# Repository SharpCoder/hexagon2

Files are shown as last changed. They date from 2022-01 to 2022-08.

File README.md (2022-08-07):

# hexagon2

Hexagon wall v2

Final product

## Installation

To properly build the hexagon2 project, you'll need the following:

```bash
# Install build tools
sudo apt-get install gcc-arm-none-eabi jq

# Configure rust
rustup default nightly
rustup target add thumbv7em-none-eabi
```

## Building

In order for your project to build correctly, you'll need to run the following command:

```
./build.sh
```

The build script will generate a `.hex` file and place it in a folder called `out`. This hex file is compatible with the teensy 4.0 and can be flashed with the teensy-loader utility.

**CAUTION**: Do not build this in release mode. It optimizes a lot of stuff away, and can cause problems.

## Bill of Materials

### Brain

- 1x [DC Barrel Jack](https://www.sparkfun.com/products/10811)
- 1x DS18B20
- 1x 4.5k Resistor
- 1x 100uf Capacitor
- 1x [ESP8266](https://www.amazon.com/dp/B010N1ROQS)
- 1x [Teensy4.0](https://www.sparkfun.com/products/16997)
- 3x [WS2812b SMD](https://www.sparkfun.com/products/16346)

### Unit

- 3x [WS2812b SMD](https://www.sparkfun.com/products/16346)
- 2x Right-Angle Headers

### Hardware (per unit)

- 1x M4x12 Bolt
- 1x M4 Nut
- 2x M4 Washers

### Circuits

There are two circuit boards which need to be fabricated. The gerber files are located in the `gerber/` folder. You will need:

- 1x brain_v1.x.zip
- nx unit_v1.x.zip

You need 1 brain per project and as many units as you like. Each hexagon will require 1 unit.

_NOTE_ There is SMD soldering required for this project. If you don't want to solder yourself, a BOM and Pick and Place file are included inside the unit.1.x.zip file. This only applies to the individual hexagon units. Brain still has to be manually assembled.

### Power Warning!!!

Each WS2812B takes 50mA and one hexagon unit has 3 of those. So that means you're looking at 150mA draw per hexagon unit. The trace in all the circuits (as of the August 6th upload) is pretty thick (1mm) which can support 2.3A with 10 degrees (C) of thermal dissipation. That is about 15 hexagon units that you can string together before you'll reach capacity. You can go more, but things will start getting toasty.

To mitigate this problem, all boards have a "POWER JUMPER" section. You can connect wire to the POWER JUMP (like, say, 18 guage wire) and splice it in throughout the final assembly. in this way, you can route the power in a much more controlled fashion.

### 3D Printed

There are a few parts which need to be 3D printed. You can find everything in the `3d/` folder. The important things are pre-generated in .STL format. You can also find all the openscad source code for each object.

- hexcore.stl
- hexshield.stl
- snapfit.stl

---

### hexcore.stl

This is the actual hexagon which you will mount the circuitry to.

**Infill** 15 or 20%

**Pattern** Rectilinear is fine

**Material** PLA Recommended

**Color** White

---

### hexshield.stl

This is the faceplate which attaches to each hexagon node using a friction-fit mechanism.

**Infill** 100%

**Pattern** Rectilinear **Required**

**Material** PETG Recommended

**Color** Transparent

---

### snapfit.stl

This is the little snapfit connector that you can use to attach hexagons together.

**Infill** 15 or 20%

**Pattern** Rectilinear is fine

**Material** PLA recommended

**Color** Any

---

## License

[MIT](https://choosealicense.com/licenses/mit/)

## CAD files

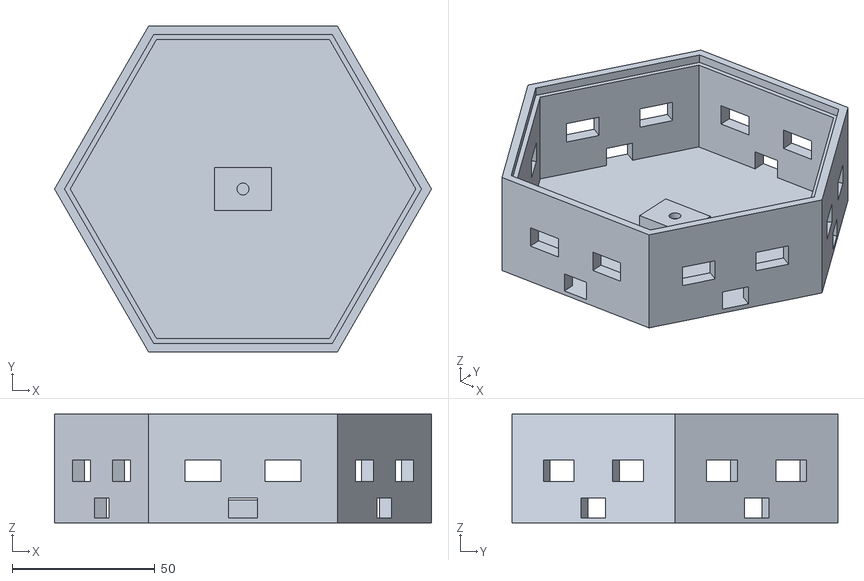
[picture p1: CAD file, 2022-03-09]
3d/hexcore.stl
132.0 x 114.3 x 38.0

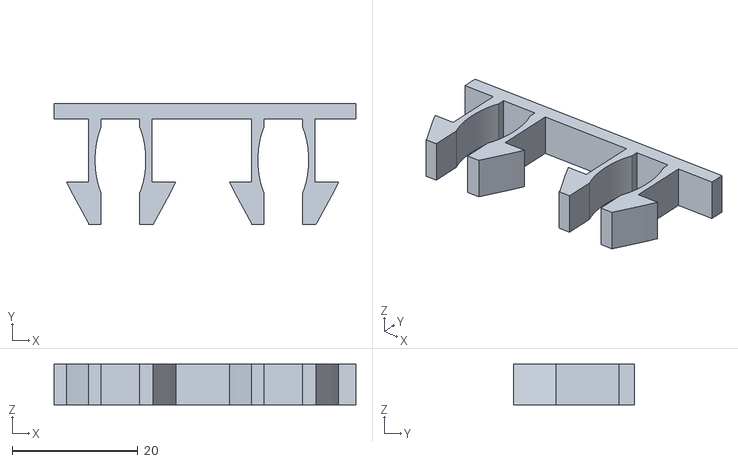
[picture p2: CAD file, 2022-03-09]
3d/snapfit.stl
48.0 x 19.2 x 6.45

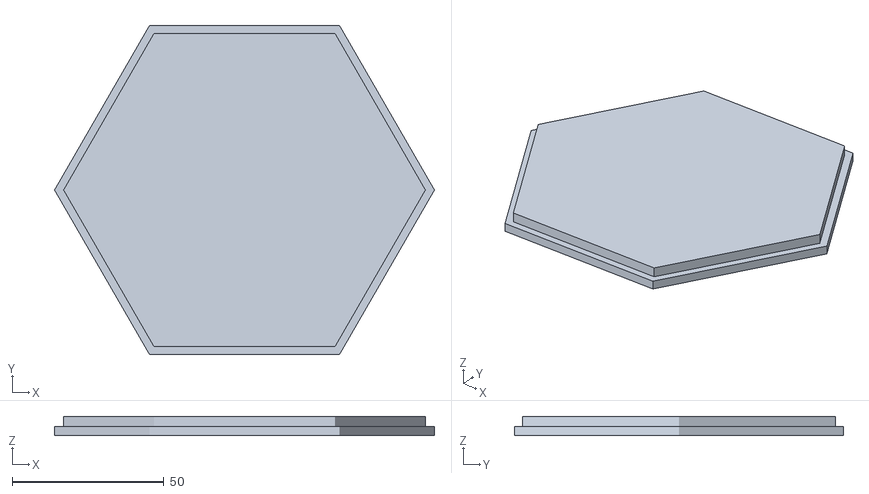
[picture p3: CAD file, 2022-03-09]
3d/hexshield.stl
125.4 x 108.6 x 6.40

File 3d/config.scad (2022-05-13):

HEX_WIDTH= 125;
HEX_BORDER = 7;
HEX_HEIGHT = 38;
HEX_ARM = HEX_WIDTH / 6;
SHIELD_THICKNESS = 3;
SHIELD_DIFFUSER_PADDING = 1;

SNAPFIT_DEPTH = 12.5;
SNAPFIT_HEIGHT = 7.5;

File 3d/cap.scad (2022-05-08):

$fn=100;

    difference() {
        union() {
            linear_extrude(1.5)
            circle(d=37);
            
            color("red")
            linear_extrude(3)
            circle(d=35);
        }
        
        linear_extrude(100)
        translate([0, 25/2+2, 0])
        circle(d=12);
        
    }

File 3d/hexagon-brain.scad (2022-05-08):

include <hexagon-core.scad>;

module power_cord_hole() {
    translate([4,0,10])
    rotate([30,90,0])
    translate([0,0,30])
    linear_extrude(50)
    circle(d=18, $fn=100);
}

module wire_channel() {
    translate([14, 0, 11.6])
    translate([-14, 0, -11])
    linear_extrude(8)
    translate([0,50,0])
    square([10, 50], center=true);
    
}

difference() {
    hexagon_core();
    union() {
        translate([-30,-2,5.5+5])
        power_cord_hole();
        
        translate([0,0,6])
        rotate(60)
        wire_channel();
    }
}

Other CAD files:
3d/hexagon-core.scad
3d/hexagon-shield.scad
3d/pcb-mount.scad
3d/plating.scad
3d/snap-prototype2.scad
3d/stand.scad
3d/wall-mount.scad
3d/washer.scad

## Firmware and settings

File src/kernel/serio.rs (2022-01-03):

/** 
 * This module represents the serial communication protocol
 * based on UART physical hardware. For simplicity, it is tightly
 * coupled to a specific uart device.
*/
use crate::phys::uart::*;
use crate::phys::irq::*;
use crate::phys::pins::*;

const UART_BUFFER_SIZE: usize = 512; // bytes
static mut UART1: Uart = Uart::new(Device::Uart1, /* TX Pin */ 24, /* RX Pin */ 25, /* IRQ */ Irq::Uart1);
static mut UART2: Uart = Uart::new(Device::Uart2, 14, 15, Irq::Uart2);
static mut UART3: Uart = Uart::new(Device::Uart3, 17, 16, Irq::Uart3);
static mut UART4: Uart = Uart::new(Device::Uart4, 8, 7, Irq::Uart4);
static mut UART5: Uart = Uart::new(Device::Uart5, 1, 0, Irq::Uart5); // NOTE: THIS DEVICE DOESN'T HAVE VALID PINS
static mut UART6: Uart = Uart::new(Device::Uart6, 1, 0, Irq::Uart6);
static mut UART7: Uart = Uart::new(Device::Uart7, 29, 28, Irq::Uart7);
static mut UART8: Uart = Uart::new(Device::Uart8, 20, 21, Irq::Uart8);

#[derive(Clone, Copy)]
pub enum SerioDevice {
    Uart1 = 0x0,
    Uart2 = 0x1,
    Uart3 = 0x2,
    Uart4 = 0x3,
    Uart5 = 0x4,
    Uart6 = 0x5,
    Uart7 = 0x6,
    Uart8 = 0x7,
}

/** 
    This encapsulates an entire Uart device
    being instantiated, including all necessary memory
    and mappings.
*/
struct Uart {
    device: Device,
    tx_pin: usize,
    rx_pin: usize,
    initialized: bool,
    irq_processing: bool,
    irq: Irq,
    buffer: [u8; UART_BUFFER_SIZE],
    buffer_head: usize,
}

impl Uart {
    pub const fn new(device: Device, tx_pin: usize, rx_pin: usize, irq: Irq) -> Uart {
        return Uart {
            device: device,
            buffer: [0; UART_BUFFER_SIZE],
            buffer_head: 0,
            initialized: false,
            irq_processing: false,
            tx_pin: tx_pin,
            rx_pin: rx_pin,
            irq: irq,
        }
    }

    fn initialize(&mut self) {
        // Initialize the pins
        pin_mux_config(self.tx_pin, Alt::Alt2);
        pin_pad_config(self.tx_pin, PadConfig {
            hysterisis: true,
            resistance: PullUpDown::PullDown100k,
            pull_keep: PullKeep::Keeper,
            pull_keep_en: false,
            open_drain: false,
            speed: PinSpeed::Max200MHz,
            drive_strength: DriveStrength::MaxDiv3,
            fast_slew_rate: true,
        });
        
        uart_disable(self.device);
        uart_sw_reset(self.device, true);
        uart_sw_reset(self.device, false);
        uart_configure(self.device, UartConfig {
            r9t8: false,
            invert_transmission_polarity: false,
            overrun_irq_en: false,
            noise_error_irq_en: false,
            framing_error_irq_en: false,
            parity_error_irq_en: false,
            tx_irq_en: false,
            rx_irq_en: false,
            tx_complete_irq_en: false, // true
            idle_line_irq_en: false,
            tx_en: false,
            rx_en: false,
            match1_irq_en: false,
            match2_irq_en: false,
            idle_config: IdleConfiguration::Idle16Char,
            doze_en: false,
            bit_mode: BitMode::EightBits,
            parity_en: false,
            parity_type: ParityType::Even,
        });
    
        uart_configure_fifo(self.device, FifoConfig {
            tx_fifo_underflow_flag: false,
            rx_fifo_underflow_flag: false,
            tx_flush: false,
            rx_flush: false,
            tx_fifo_overflow_irq_en: false,
            rx_fifo_underflow_irq_en: false,
            tx_fifo_en: true,
            tx_fifo_depth: BufferDepth::Data128Words,
            rx_fifo_en: false,
            rx_fifo_depth: BufferDepth::Data1Word,
        });
    
        pin_mode(self.tx_pin, Mode::Output);
        uart_set_pin_config(self.device, InputTrigger::Disabled);
        uart_disable_fifo(self.device);
        
        uart_watermark(self.device);
        uart_enable(self.device);
        
        pin_out(self.tx_pin, Power::Low);
        
        irq_attach(self.irq, serio_handle_irq);
        irq_enable(self.irq);

        uart_baud_rate(self.device, 9600.0);

        self.initialized = true;        
    }

    pub fn write(&mut self, bytes: &[u8]) {
        if !self.initialized {
            self.initialize();
        }

        let mut byte_idx = 0;
        while byte_idx < bytes.len() {
            self.enqueue(bytes[byte_idx]);
            byte_idx += 1;
        }
    }

    fn enqueue(&mut self, byte: u8) {
        disable_interrupts();
        
        // Make sure we're not buffer overflowed
        if (self.buffer_head + 1) >= UART_BUFFER_SIZE {

            crate::err();
            return;
        }

        self.buffer[self.buffer_head] = byte;
        self.buffer_head += 1;

        if self.buffer_head == 1 {
            pin_out(self.tx_pin, Power::High);
            uart_set_reg(self.device, &CTRL_TCIE);
        }

        enable_interrupts();
    }

    fn dequeue(&mut self) -> Option<u8> {
        // This would def be a no-hire if it were an interview :P
        if self.buffer_head > 0 {
            disable_interrupts();
            // Take the head element
            let result = self.buffer[0];

            // Shift everything over to the left
            let mut idx = 0;
            while idx < self.buffer_head {
                self.buffer[idx] = self.buffer[idx + 1];
                idx += 1;
            }

            // Decrement the head
            self.buffer_head -= 1;
            enable_interrupts();
            return Some(result);
        } else {
            return None;
        }
    }

    pub fn handle_irq(&mut self) {
        // Don't process a uart device that hasn't
        // been used
        if !self.initialized || self.irq_processing {
            return;
        }
        disable_interrupts();
        
        
        // This prevents circular calls
        self.irq_processing = true;

        // If tx is empty
        if uart_get_irq_statuses(self.device) & (0x1 << 23) > 0 {
            match self.dequeue() {
                None => {
                    // Disengage, I guess?
                    uart_clear_reg(self.device, &CTRL_TCIE);
                    
                },
                Some(byte) => {
                    // Clear TSC
                    uart_disable(self.device);
                    uart_enable(self.device);
                    uart_sbk(self.device);

                    // Get the next byte to write and beam it
                    uart_write_fifo(self.device, byte);
                }
            }
        }

        self.irq_processing = false;
        uart_clear_irq(self.device);

        enable_interrupts();
    }
}
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

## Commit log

2021-12-26 Interrupts are enabled
2021-12-26 Improve interrupts and wire them up with rust
2021-12-28 Have periodic timers actually working ffs
2021-12-28 Some uart stuff
2021-12-28 aweh yeah, make the clock not even use interrupts
2021-12-28 Snapshot of receiving an interrupt from uart
2021-12-28 DMA support
2021-12-29 Add some crazy functions and more dma stuff
2021-12-29 Have DMA system resetting the interrupts finally
    [serio.rs]
2021-12-29 Add arduino pin mapping and a pin library
2021-12-30 Fix major bug with pin system
    [serio.rs]
2021-12-30 UART IS DOING A THING
2021-12-30 Well, baud rate is correct
    [serio.rs]
2021-12-30 snapshot of some changes before goign down a rabbit hole regarding clock speed
2021-12-31 Vastly improve serio but no longer can you compile
    [serio.rs]
2022-01-01 just... never again... this fixes the NVIC which was constantly being offset based on the amount of global memory usage. and then this fixes the uart system completely.
    [serio.rs]
2022-01-01 Interrupts are really fixed
    [serio.rs]
2022-01-02 Fix clock cycle stuff and implement a WS2812 driver
2022-01-03 Fix bug with memory class and ws2812 driver
2022-01-03 Migrate blinking logic so it is threaded with a gate mechanism
2022-01-04 fix bug with itoa_u64 and improve debug output
    [serio.rs]
2022-01-04 Fix bugs with ws2812 driver, add random generator, add registers to shader, refactor how shaders work
    [serio.rs]
2022-01-06 Wifi driver can at least return AT now
2022-01-07 Fix the dropped character with initial message in serial write
    [serio.rs]
2022-01-07 Serial IO is working extremely well now and wifi driver is similarly stable
2022-01-08 Ability to make http requests and successfully download current time
2022-01-08 Fix uart some more
    [serio.rs]
2022-01-10 Fix the periodic timer clock, working on improving the ws2812
    [serio.rs]
2022-01-11 Refactor kalloc, fix baud issue with wifi, new driver concept for ws2812
2022-01-14 Take dependency on teensycore instead
2022-01-15 most of the driver written for max31820
2022-01-17 chores. including an unused time task for debugging, changes to thermal task and max21820 driver, and other stuff
2022-01-19 implementing new drivers, use new core
2022-01-19 Add a bunch more AT commands to the esp8266 driver
2022-01-20 remove unused legacy wifi driver
2022-01-28 initial commit of 3d models
    [config.scad, hexagon-core.scad, hexagon-shield.scad]
2022-01-29 working snap-fit mechanism
    [config.scad, hexagon-core.scad, snap-mate-prototype.scad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]
2022-01-29 improvements to the snap fit mechanism
    [pcb-mount.scad, snap-prototype2.scad]
2022-01-31 nearly there with the models
    [config.scad, pcb-mount.scad, pcb.scad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]
2022-02-03 3d model release candidates
    [config.scad, hexagon-core.scad, hexagon-shield.scad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]
2022-02-21 snapshot of whatever this is
    [config.scad, hexagon-core.scad, hexagon-shield.scad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]
2022-02-23 Update 3d models. Improve ws2812 driver
    [config.scad, hexagon-shield.scad, pcb.scad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]
2022-02-27 snapshot of changes for hexagon light task
    [config.scad, hexagon-shield.scad]
2022-03-05 cleanup stuff. add new effects database. implement a naiive form of transition
    [config.scad, hexagon-shield.scad, stand.scad]
2022-03-05 Rewrite transition code
    [config.scad]
2022-03-05 updates to wifi task
    [config.scad, hexagon-shield.scad]
2022-03-08 config based theme selection
    [brain.scad, config.txt, stand.scad]
2022-03-09 Update cargo.lock so it references the newly published version of teensycore
2022-03-09 Update carago.toml so it points to the published version of teensycore.
    [brain.scad, wall-mount.scad]
2022-03-09 Update README. Add gerber files. Add STL files
    [hexagon-core.scad, hexcore.stl, hexshield.stl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]
2022-03-10 Updates to 3d models. Updates to Shader and Effect to better control the offline sequencing
    [hexagon-brain.scad, hexagon-core.scad, stand.scad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]
2022-03-19 Update gerber. Add some more color themes
    [hexagon-brain.scad, stand.scad]
2022-05-08 Changes to clock system
    [cap.scad, config.scad, hexagon-brain.scad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]
2022-05-08 Remove overflow code
    [hexagon-shield-opaque.scad]
2022-05-08 Improve the color combos and effects
    [hexagon-shield-opaque.scad]
2022-05-13 A bunch of changes
    [config.scad, hexagon-shield.scad]
2022-05-14 Convert rgb to hsv so we can clamp the s part
2022-05-15 Point cargo.toml to the publically released version of teensycore
2022-05-25 Update gerber file
2022-08-07 update gerbers and remove code
